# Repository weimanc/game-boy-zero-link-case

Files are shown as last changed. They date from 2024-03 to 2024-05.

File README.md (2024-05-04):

# game-boy-zero-link-case
Simple case for game-boy-zero-link-cable
The scale is 3:10 (0.3x) with exception of the model thinkness.

Features:
- Top and bottom sandwiched the main PCB. The PCB edge is visable from the sides.
- The two buttons of the RP2040 board are still usable as DPAD(RESET) and AB(BOOTSEL).
- The housing completes the DMG and GBC/GBA PCB edge cconnector.
- USBC cut out.
- Two M2 8mm are needed for assembly.

# 3D printing settings
- PLA Parts (all with exception of the screen)
-- Temperature 
-- Wall count
-- 
-- infill
-- Support
-- Support infill 
- Screen (PETG)
-- 

# references
https://upload.wikimedia.org/wikipedia/commons/4/41/Gameboy.svg
https://grabcad.com/library/nintendo-game-boy-2
https://grabcad.com/library/gameboy-game-cartridge

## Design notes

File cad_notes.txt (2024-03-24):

CAD Order of operations

#helper parts:

screwpost:
- pad sketch
- mirror

speaker grill:
- master sketch_speaker_grill, one grill
- clone sketch and transform back to origin
- draft wb; array 6; sketch_speaker_grill
- pad; symmetric 10mm
- transform back
- cut with top-body  
- Z offset

Top:
- sketch-top-outline
- pad gbz_top_height
- boolean difference speaker cut
# make shell, thickness althernative
# https://old.reddit.com/r/FreeCAD/comments/v8qten/cant_add_thickness_feature/
- curves wb, select shell faces
- curves wb, misc -> parametric solid 
- 3D offset, -1.6mm, intersect
- create solid
- boolean difference (with the top body, the one that is a solid)
- fillet top edges gbz_fillet_radius
- union with screwposts
- cut with all cutout objects (screen, lcd, buttons, usbc)
- chamfer on insides (for strength)
- fillet holes for buttons
- union select buttons
- fillet dpad; ab

bottom
- sketch-bottom-outline
- pad gbz_bottom_height
# make shell, thickness althernative
- curves wb, select shell faces
- curves wb, misc -> parametric solid 
- 3D offset, -1.6mm, intersect
- create solid
- boolean difference (with the bottom body, the one that is a solid)
- fillet bottom edges 
  - gbz_grid_radius on bottom and corners edges
  - 2mm on top edge (gbz_fillet_radius too aggressive)
  - 2mm on insides
- cut grip texture
- union with screwposts

issues:
* button wall crashes in to button on the rp2040zero
* button wall prevents AB button to be inserted
- link port height (tolerance) need to increase to account the overhangs
- link port outer walls are very thin
- should create a 3rd part of the gameboy (think cartridge) to address the link port
* bottom screw pole is too tight, biting on the screw threads
* might want to reduce the length of the screw poles, so the screw force will translate to the shell walls
- overhang junk inside the LCD window.
* start/select was amputated off

Issues:
+ increase pcb-tol 0.3 -> 0.4
+ elephant foot, add chamfer:
++ link_base
++ button inserts
++ cartridge 
+ cartridge grooves lost in detail
+ bottom no screw holes
** caused by increasing gbz_bottom_height, but the offset001 is still stuck on old sizes
** cut holes
- link port vs pcb doesnt look right
* wall too thin, reduce with GBC width1 10 -> 9.8

- support on screwpost close the holes -> need to fix during slicing

* insert to button pivot

issues:
+ tolerance on link cut
+ increase cartridge stick up

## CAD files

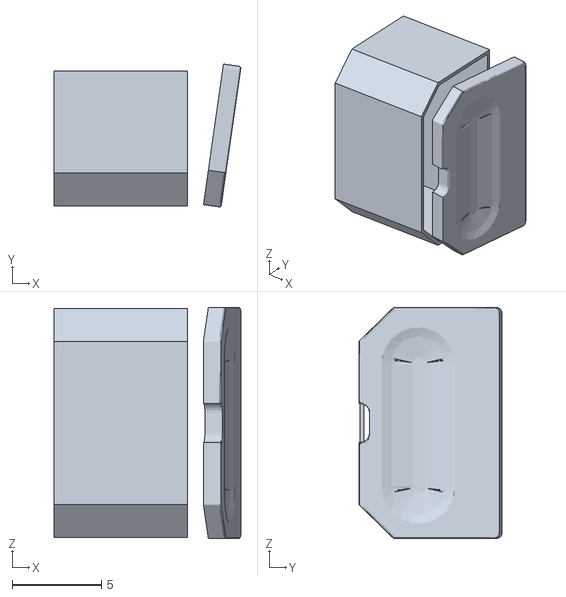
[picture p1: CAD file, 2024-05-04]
references/gbobjfullsize_extport.obj
10.5 x 8.03 x 13.0

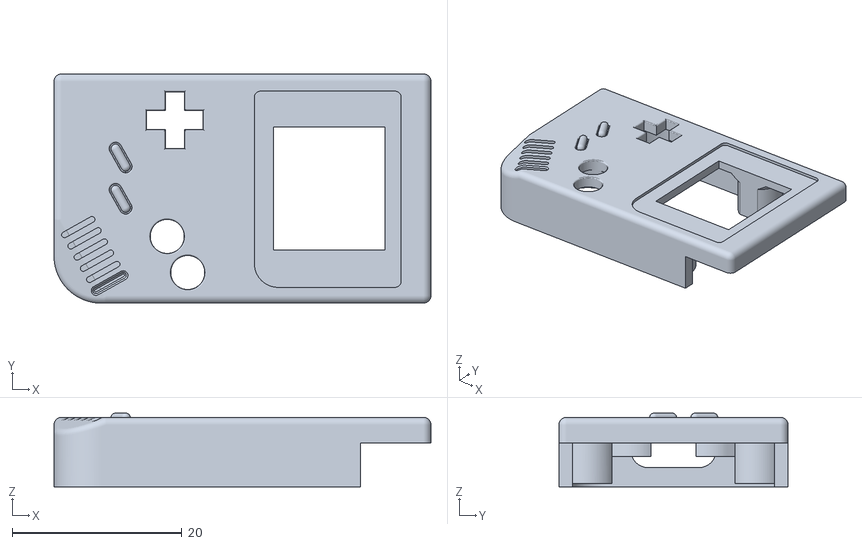
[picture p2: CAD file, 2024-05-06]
stepfiles/game-boy-zero-link-case-top_link_cut.stl
44.4 x 27.0 x 8.70

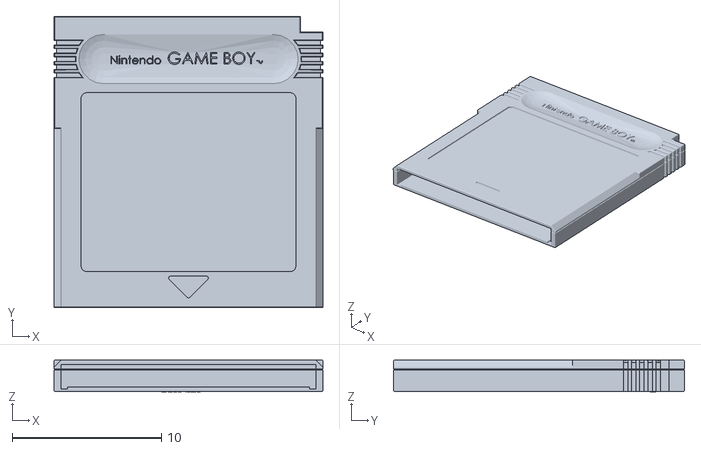
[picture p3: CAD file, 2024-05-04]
references/game-boy-zero-link-case-CARTRIDGE_0.3.obj
18.0 x 19.5 x 2.13

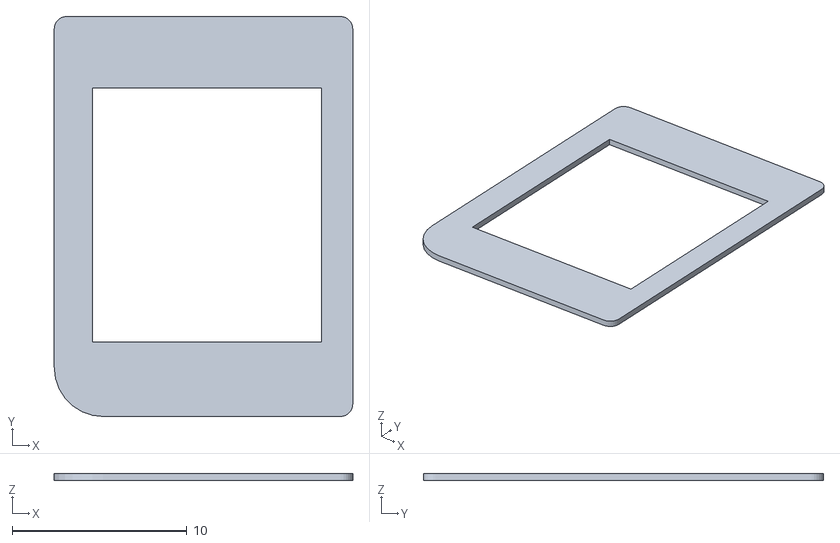
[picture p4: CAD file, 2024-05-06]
stepfiles/game-boy-zero-link-case-screen_frame.stl
17.1 x 22.9 x 0.4

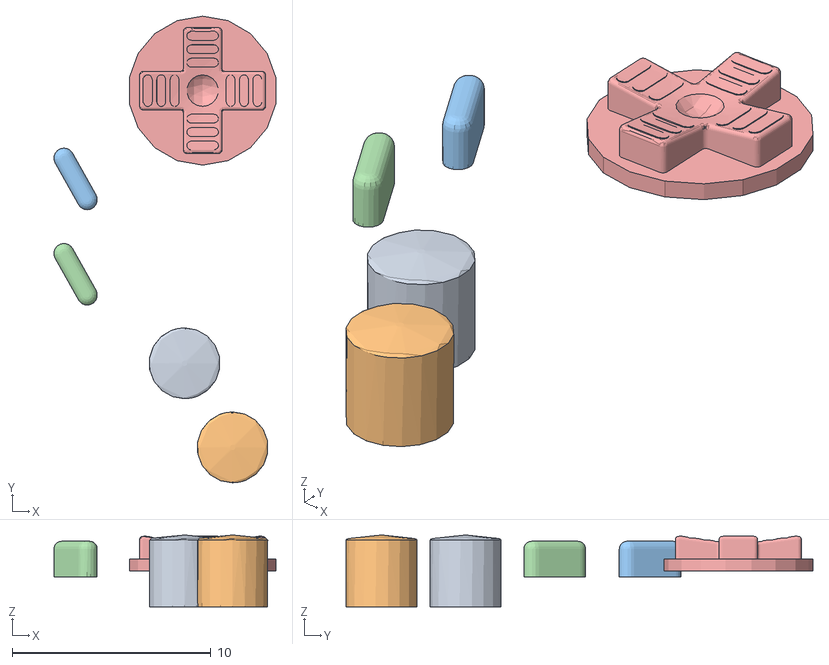
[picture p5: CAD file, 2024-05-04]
references/gbobj_button_ab.obj
11.2 x 23.5 x 3.60
button_b
button_a
button_select
button_start
dpad

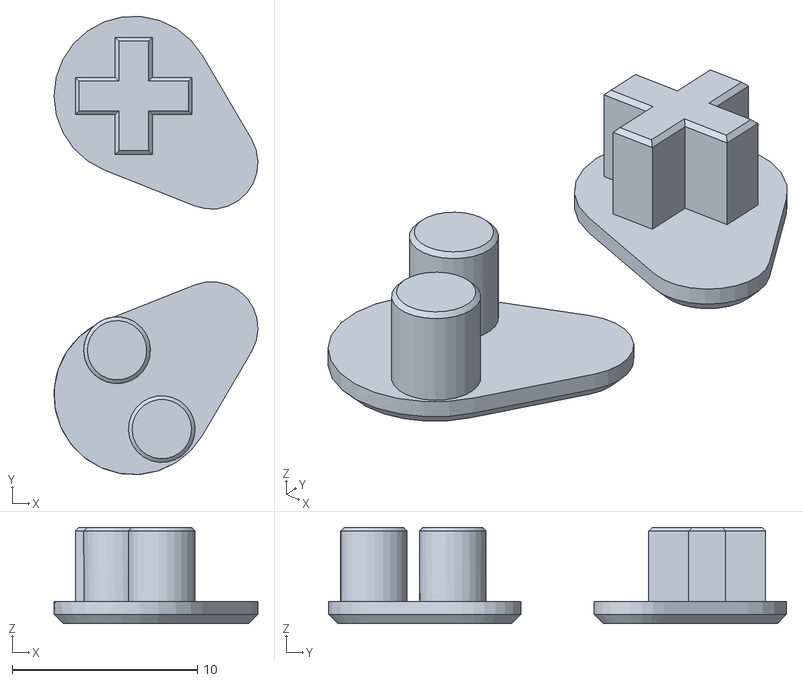
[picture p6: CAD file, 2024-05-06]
stepfiles/game-boy-zero-link-case-buttons_dpad_ab_insert.stl
11.0 x 24.7 x 5.20

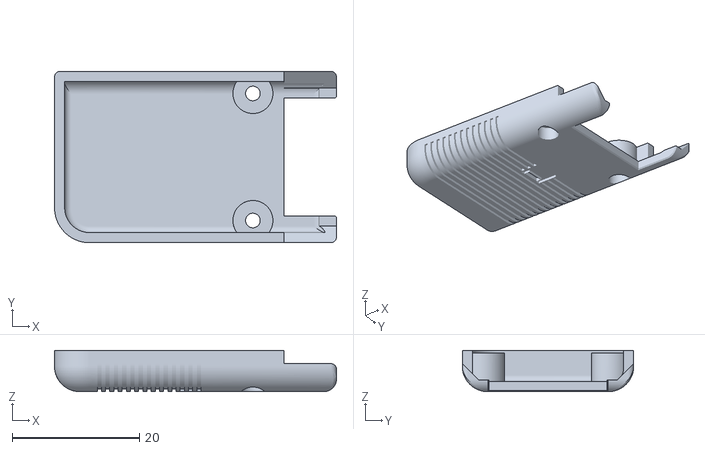
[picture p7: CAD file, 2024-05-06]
stepfiles/game-boy-zero-link-case-bottom_link.stl
44.4 x 27.0 x 6.50

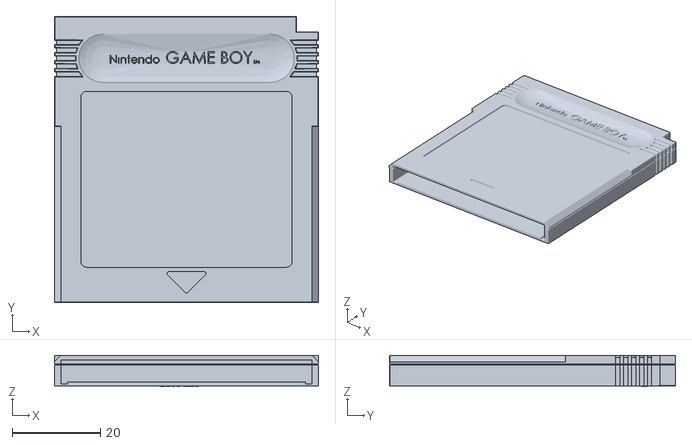
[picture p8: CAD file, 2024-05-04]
references/game-boy-zero-link-case-CARTRIDGE.obj
60.0 x 65.0 x 7.10

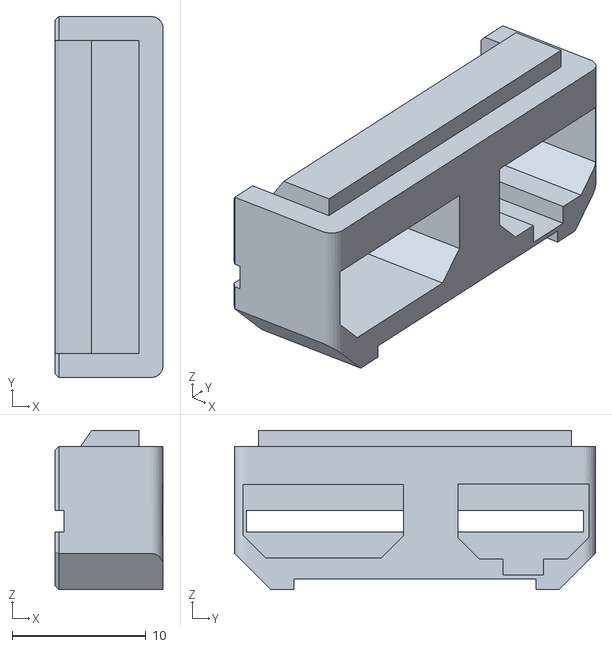
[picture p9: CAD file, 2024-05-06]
stepfiles/game-boy-zero-link-case-link_base_chamfer.stl
8.10 x 27.0 x 11.9

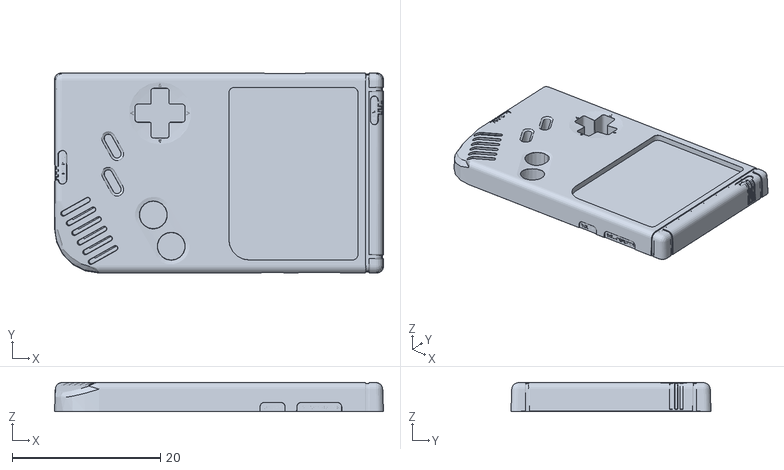
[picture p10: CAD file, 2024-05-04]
references/gbobj_case_top.obj
44.4 x 27.0 x 3.92

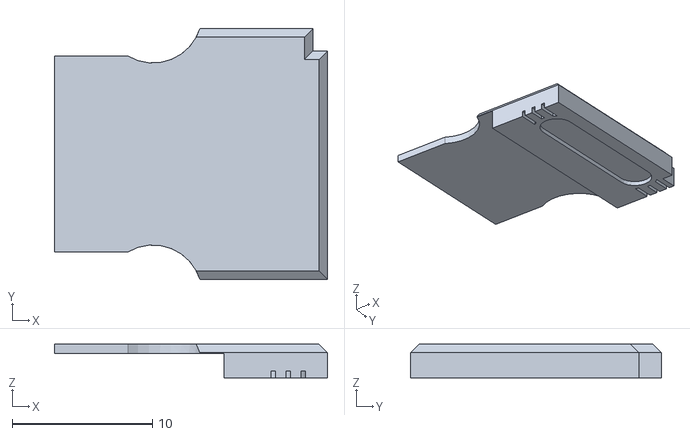
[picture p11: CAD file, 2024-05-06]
stepfiles/game-boy-zero-link-case-cartridge_grooved.stl
19.5 x 17.9 x 2.40

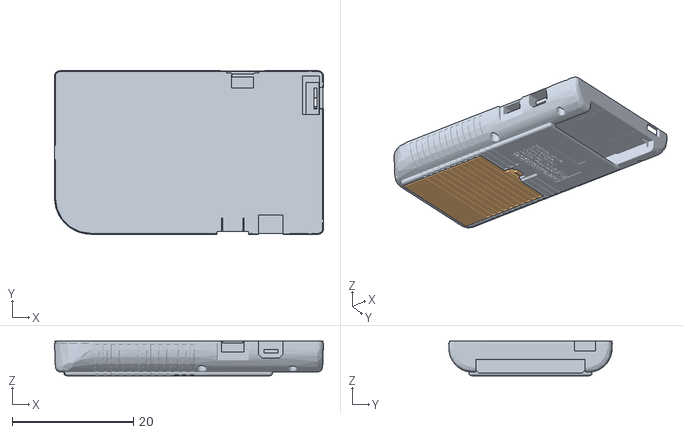
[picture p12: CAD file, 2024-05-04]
references/gbobj_case_bottom.obj
44.4 x 27.0 x 5.70
case.001
case_batt.001

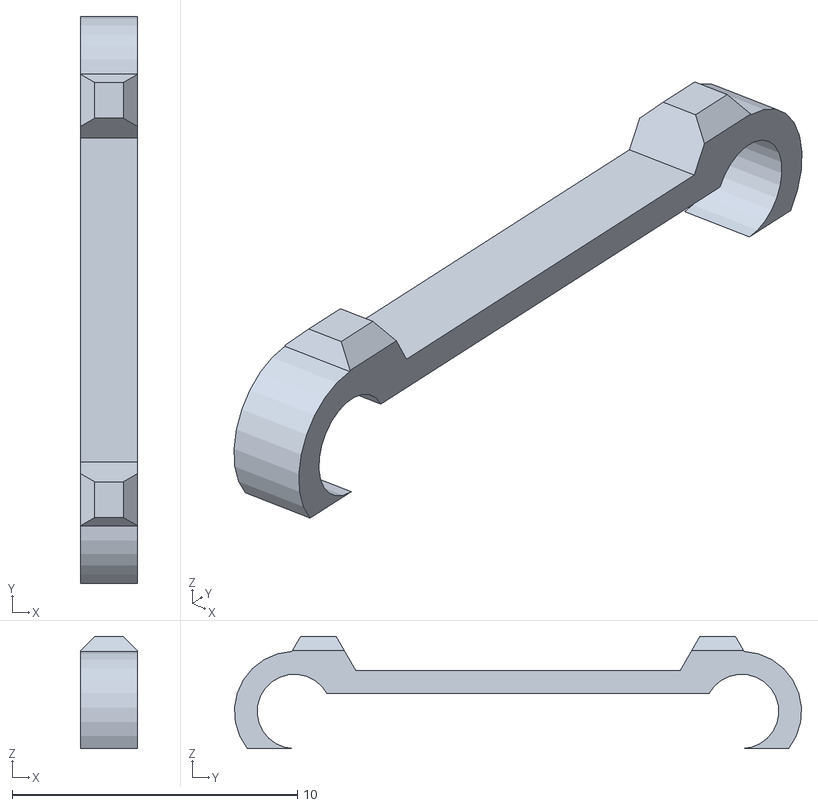
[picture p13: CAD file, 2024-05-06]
stepfiles/game-boy-zero-link-case-buttons_pivot.stl
2.00 x 19.9 x 3.93

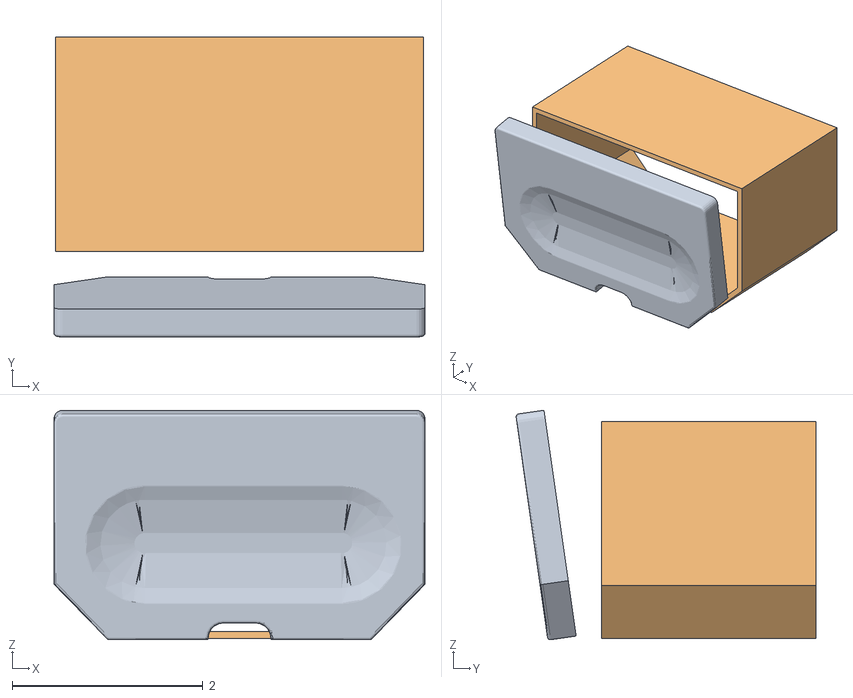
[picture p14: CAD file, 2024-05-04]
references/gbobj_extport.obj
3.89 x 3.15 x 2.41
ext_cover
exit_port

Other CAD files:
references/gbobj_button_startselect.obj
stepfiles/game-boy-zero-link-case-screen_frame_petg_long.stl
references/gbobj_screen.obj
references/gbobj_button_dpad.obj

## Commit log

2024-02-23 created cut outs for dpad, ab and screen added screw posts
2024-03-03 update PCB model after changing 1.2 thickness
2024-03-10 add cad_notes.txt ready for proto2 print - testing buttons - add some details on top shell - reinforce the screwposts
2024-03-10 proto2, buttons insert was too thick
2024-03-11 made cut outs for the two link port types (minus PCB thickness)
2024-03-13 modelled the two link ports housings started on the bottom half created grip array for cut out created bottom screw post and cut out
2024-03-17 bottom shell done with grip and screw holes
2024-03-19 prototype3 printed. issues: - button wall crashes in to button on the rp2040zero - button wall prevents AB button to be inserted - link port height (tolerance) need to increase to account the overhan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
2024-03-23 modelled battery clip, gb cartridge cut bottom and top
2024-03-23 prototype4 ready for print
2024-03-24 prototype 4.1 ready to print fixed issues: + increase pcb-tol 0.3 -> 0.4 + elephant foot, add chamfer: ++ link_base ++ button inserts ++ cartridge + cartridge grooves lost in detail + bottom no screw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
2024-03-24 4.2 added button pivot, printed, adjusted cad to improve clip increased cartridge thickness, slimmed down cartridge to make it insertable.
2024-03-30 prototype 4.4 -link add more margin for cartridge depth -rgb_lightpipe fix collision with buttons -screen_click add margin for smoother insert
2024-04-14 prototype 5.1 - screen insert for PETG printing
2024-05-04 clean up directory structure add some references to README.md
    [game-boy-zero-link-case-CARTRIDGE.obj, game-boy-zero-link-case-CARTRIDGE_0.3.obj, gbobj_button_ab.obj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]
2024-05-06 add stepfiles
    [game-boy-zero-link-case-bottom_link.stl, game-boy-zero-link-case-buttons_dpad_ab_insert.stl, game-boy-zero-link-case-buttons_pivot.stl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]
